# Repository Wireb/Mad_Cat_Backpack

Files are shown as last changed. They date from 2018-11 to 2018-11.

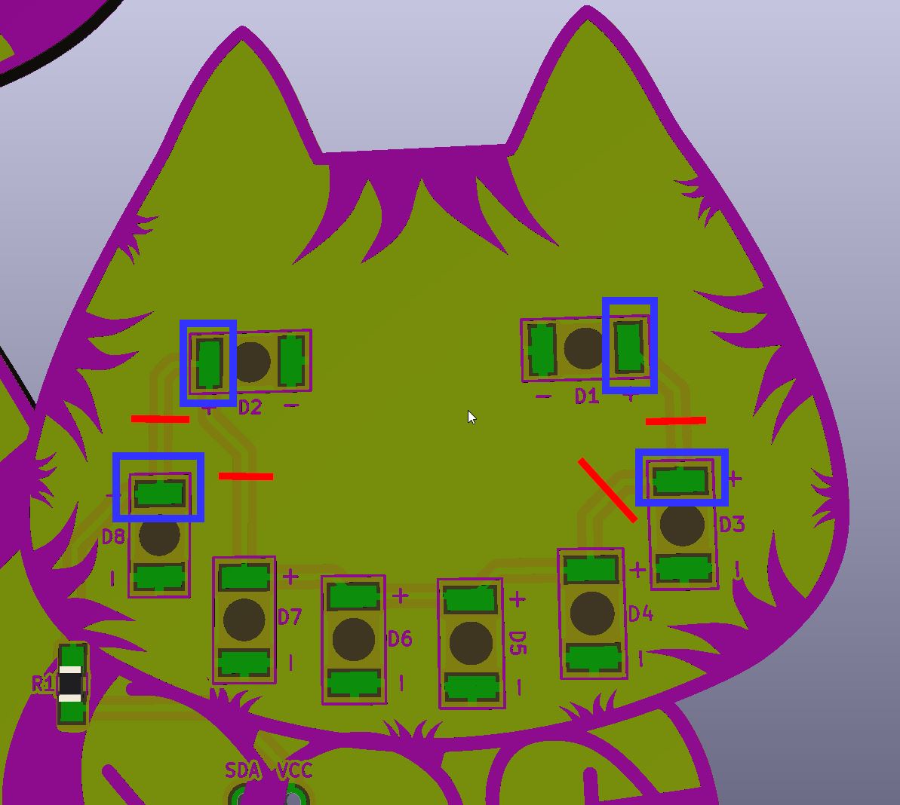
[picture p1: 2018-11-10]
Mad_Cat_modificatons.jpg

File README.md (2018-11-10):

# Mad Cat Backpack
The Mad Cat Backpack is a animation upgrade for Mr TwinkleTwinkie's Mad Cat SAOs.
 
License is MIT so do what you want with it just don't litigate me. 

Current firmware runs a loop that waits a random amount of time between 0 and 8 minutes then picks a random animation. 

Current animations:
1. classic fade out fade in (random off delay)
2. blink / wink (random length random eye (left, right, or both) 
3. lip lick rights
4. lip lick left
5. piano teeth (random number of loops) 
6. eye bobble (random number of loops)
7. talking (random number of loops) 
8. sparkles (all random) 

Animations are NOT weighted evenly. Blinking has a higher probability then the others while sparkles has the least. 

Total code space use is ~36% so plenty of space for more animations if wanted. 

**NOTE** 
- When running off 5V power the LEDs are borderline too bright. Replace the 200 ohm resistors with a larger value to reduce brightness.

## KiCad
This is a KiCad 5.0 project. 
PCBs are also posed on OSHpark here: https://www.oshpark.com/shared_projects/GfiURq3q

## MplabX
This is a mplabX 5.05 project. All programming / debug was done with a PicKit4.
The firmware source is all contained in mad_cat_backpack_v0.asm 
If you just want to program a backpack using mad_cat_backpack.X.production.hex in microchip IPE is the fastest way. 

## Documentation
There is not much for documentation on this one. 

First you need a Mad Cat SAO from Mr TwinkleTwinkie:
- https://www.tindie.com/products/twinkletwinkie/twinkletwinkies-badgelife-sao-add-on-4/
- https://hackaday.io/project/159523-mad-cat

Next you need a backpack PCB:
- https://www.oshpark.com/shared_projects/GfiURq3q

Parts list for the backpack are:
 - 1x PIC16F1503-I/SL https://www.digikey.com/product-detail/en/microchip-technology/PIC16F1503-I-SL/PIC16F1503-I-SL-ND/2772041
 - 1x 10uF 10V or greater 0805 ceramic cap https://www.digikey.com/product-detail/en/samsung-electro-mechanics/CL21A106KPFNNNG/1276-6456-1-ND/5958084
 - 8x 200 ohm 0805 resistors (see note above about brightness) https://www.digikey.com/product-detail/en/yageo/AC0805JR-07200RL/YAG3769CT-ND/6006618
 - Optional 1x UJ2-MBH-1-SMT-TR mini USB jack https://www.digikey.com/product-detail/en/cui-inc/UJ2-MBH-1-SMT-TR/102-4003-1-ND/6187925
 - 8x white LEDs (reused the ones from the Mad Cat kit) 

 Assemble the back pack first. I just used a iron and tweezers to assemble mine. The LED pads ARE oversized to match the footprints on the Mad Cat. Center the LED between the pads and bridge the solder over to the terminals. Make sure the solder bridges are not taller thant the body of the LED. 

 Load the firmware using the 5 pads in the center of the board. The square pin is pin 1. 

 Test the backpack by plugging in power or USB. THe smile should dim in first then the eyes if so all is working and ready for final assembly. 

 Before final assembly the Mad Cat PCB needs to be modified. Look at Mad_Cat_modifications.jpg Cut the 4 traces marked by a red line. Make sure they are fully open. 

 Line up the backpack on the Mad Cat PCB. I used a 4 pin header though both sets of SAO holes then visually lined up the D3 and D8 leds with the solder mask holes in the Mad Cat PCB. 

 Once everything is lined up solder the 4 pads marked in blue boxes on Mad_Cat_modifications.jpg between the Mad Cat and the backpack. To do this I used a fine point soldering iron tip and some 0.5mm diameter solder. There is just enough space to get under the edge and heat the pads and the 0.5mm solder is small enough to slide between the two boards. 

 Final option step is to add yarn between the LEDs to prevent light leakage. I used some dark colored yarn and dental threaders to thread sections between all the LEDs. When in place cut the ends of the yarn off ass close to the backpack as possible and tuck the excess under the backpack. I also wrapped a piece of yarn around the edge of the backpack to keep light from spilling out behind the Mad Cat SAO.

Copyright (c) 2018 Peter Shabino

Permission is hereby granted, free of charge, to any person obtaining a copy of this hardware, software, and associated documentation files 
(the "Product"), to deal in the Product without restriction, including without limitation the rights to use, copy, modify, merge, publish, 
distribute, sublicense, and/or sell copies of the Product, and to permit persons to whom the Product is furnished to do so, subject to the 
following conditions:

The above copyright notice and this permission notice shall be included in all copies or substantial portions of the Product.

THE PRODUCT IS PROVIDED "AS IS", WITHOUT WARRANTY OF ANY KIND, EXPRESS OR IMPLIED, INCLUDING BUT NOT LIMITED TO THE WARRANTIES OF 
MERCHANTABILITY, FITNESS FOR A PARTICULAR PURPOSE AND NONINFRINGEMENT. IN NO EVENT SHALL THE AUTHORS OR COPYRIGHT HOLDERS BE LIABLE 
FOR ANY CLAIM, DAMAGES OR OTHER LIABILITY, WHETHER IN AN ACTION OF CONTRACT, TORT OR OTHERWISE, ARISING FROM, OUT OF OR IN CONNECTION 
WITH THE PRODUCT OR THE USE OR OTHER DEALINGS IN THE PRODUCT.

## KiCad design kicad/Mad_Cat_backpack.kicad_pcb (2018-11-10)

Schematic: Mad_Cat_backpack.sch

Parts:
C1: 10uF; C_0805
D1, D2, D3, D4, D5, D6, D7, D8: LED; LED_OSRAM_TOPLED_LxT776
J1: USB_B_Mini; USB_Mini_B_Female_UJ2-MBH-1-SMT-TR
J2: PicKit; Pin_Header_Straight_1x05_Pitch2.54mm
R1, R2, R3, R4, R5, R6, R7, R8: 200; R_0805_HandSoldering
U1: PIC16F1503; SOIC-14_3.9x8.7mm_Pitch1.27mm
X1: Badgelife_shitty_connector; Badgelife-Shitty-2x2
icon1: Metroid; metroid

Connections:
+5V: C1.1, J1.1 (VBUS), J2.2, R1.1, R2.1, R3.1, R4.1, R5.1, R6.1, R7.1, R8.1, U1.1, X1.1
GND: C1.2, J1.5 (GND), J1.6 (Shield), J2.3, U1.14, X1.2
unnamed: D1.1, U1.2
unnamed: D1.2, R2.2
unnamed: D2.1, U1.7
unnamed: D2.2, R3.2
unnamed: D3.1, U1.3
unnamed: D3.2, R1.2
unnamed: D4.1, U1.10
unnamed: D4.2, R8.2
unnamed: D5.1, U1.9
unnamed: D5.2, R7.2
unnamed: D6.1, U1.8
unnamed: D6.2, R6.2
unnamed: D7.1, U1.5
unnamed: D7.2, R5.2
unnamed: D8.1, U1.6
unnamed: D8.2, R4.2
unnamed: J2.1, U1.4
unnamed: J2.4, U1.13
unnamed: J2.5, U1.12

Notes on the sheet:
Copyright (c) 2018 Peter Shabino Permission is hereby granted, free of charge, to any person obtaining a copy of this hardware, software, and associated documentation files (the "Product"), to deal in the Product without restriction, including without limitation the rights to use, copy, modify, mer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

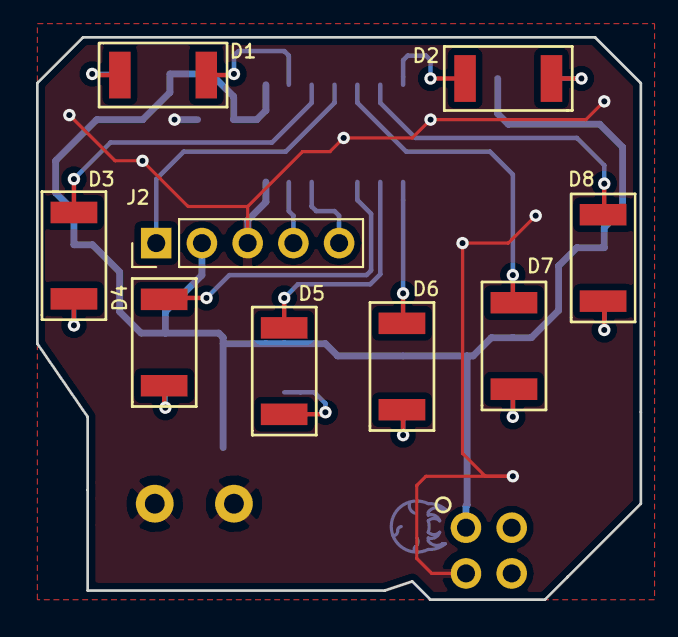
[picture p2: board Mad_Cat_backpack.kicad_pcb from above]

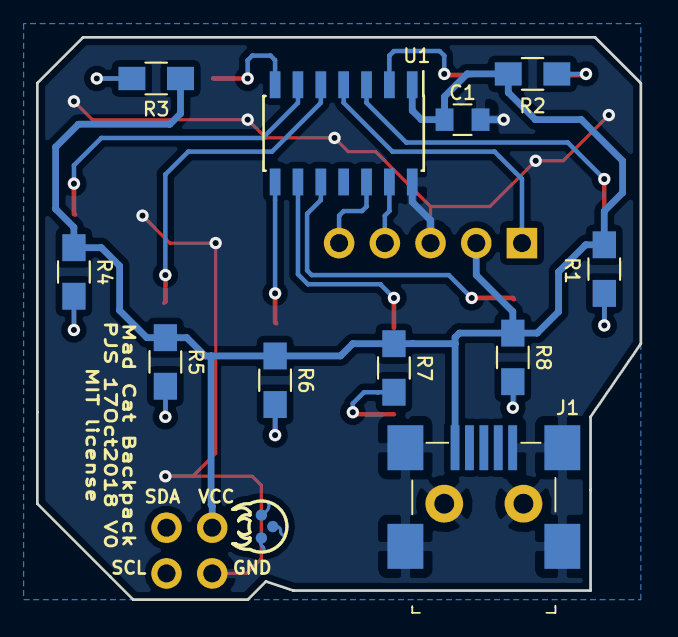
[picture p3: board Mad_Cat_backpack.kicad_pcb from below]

Board: 2 copper layers, 33.5 x 31.2 mm, 22 parts (12 on the bottom side), 21 nets.

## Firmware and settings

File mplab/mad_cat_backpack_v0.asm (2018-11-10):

;#########################################################################################################################################################
;Copyright (c) 2018 Peter Shabino
;
;Permission is hereby granted, free of charge, to any person obtaining a copy of this hardware, software, and associated documentation files 
;(the "Product"), to deal in the Product without restriction, including without limitation the rights to use, copy, modify, merge, publish, 
;distribute, sublicense, and/or sell copies of the Product, and to permit persons to whom the Product is furnished to do so, subject to the 
;following conditions:
;
;The above copyright notice and this permission notice shall be included in all copies or substantial portions of the Product.
;
;THE PRODUCT IS PROVIDED "AS IS", WITHOUT WARRANTY OF ANY KIND, EXPRESS OR IMPLIED, INCLUDING BUT NOT LIMITED TO THE WARRANTIES OF 
;MERCHANTABILITY, FITNESS FOR A PARTICULAR PURPOSE AND NONINFRINGEMENT. IN NO EVENT SHALL THE AUTHORS OR COPYRIGHT HOLDERS BE LIABLE 
;FOR ANY CLAIM, DAMAGES OR OTHER LIABILITY, WHETHER IN AN ACTION OF CONTRACT, TORT OR OTHERWISE, ARISING FROM, OUT OF OR IN CONNECTION 
;WITH THE PRODUCT OR THE USE OR OTHER DEALINGS IN THE PRODUCT.
;#########################################################################################################################################################
; 02Nov18 V0 PJS New
; 04Nov18 V1 PJS 8 base animations in with random rotations and delays. 
    
#define	CODE_VER_STRING "Peter Shabino 04Nov18 code for Mad Cat Backpack V1 www.wire2wire.org!" ;Just in ROM !!! update vars below with true level!!


;****************************************************************************************
; port list [SSOP28]
; Vss(14)
; Vdd(1)
; RA0(13)	[ICSPDAT]
; RA1(12)	[ICSPCLK]
; RA2(11)	
; RA3(4)	[#MCLR]
; RA4(3)	led tooth 1 left
; RA5(2)	led left eye
; RC0(10)	led tooth 2
; RC1(9)	led tooth 3
; RC2(8)	led tooth 4
; RC3(7)	led right eye
; RC4(6)	led tooth 6 right
; RC5(5)	led tooth 5
;****************************************************************************************

	
; PIC16F1503 Configuration Bit Settings
#include "p16f1503.inc"
; CONFIG1
; __config 0xFF04
 __CONFIG _CONFIG1, _FOSC_INTOSC & _WDTE_OFF & _PWRTE_ON & _MCLRE_OFF & _CP_ON & _BOREN_ON & _CLKOUTEN_OFF
; CONFIG2
; __config 0xF7FF
 __CONFIG _CONFIG2, _WRT_OFF & _STVREN_ON & _BORV_LO & _LPBOR_ON & _LVP_ON	
 
 
 
;------------------
; constants
;------------------	
PWM_DELAY		equ 0x7D
	
;------------------
; vars (0x20 - 0x6f) bank 0
;------------------
right_eye		equ 0x20
left_eye		equ 0x21
tooth1			equ 0x22
tooth2			equ 0x23
tooth3			equ 0x24
tooth4			equ 0x25
tooth5			equ 0x26
tooth6			equ 0x27
pwm_cnt			equ	0x28
delay_l			equ 0x29
delay_h			equ	0x2A
counter1		equ 0x2B
temp			equ 0x2C
LFSR_0			equ	0x2D			
LFSR_1			equ	0x2E			
LFSR_2			equ	0x2F			
LFSR_3			equ	0x30	
LFSR_count		equ 0x31
counter2		equ 0x32
 
 
;------------------
; vars (0x70 - 0x7F) global regs
;------------------


 
;put the following at address 0000h
	org     0000h
	goto    START			    ;vector to initialization sequence

;put the following at address 0004h
	org     0004h
	clrf	PCLATH				; this MUST be cleared before the IRQ goto else will jump to god knows where. 
	goto    IRQ			    

; stuff in the 	code description at the top of the code. 
	de	CODE_VER_STRING
	
;###########################################################################################################################
; intrupt routine
;###########################################################################################################################
IRQ		
	; following regs are autosaved
	; W
	; STATUS (except TO and PD)
	; BSR
	; FSR
	; PCLATH
	
	
	;------------------
	clrf    BSR			    ; bank 0
	;------------------
	btfss	INTCON, TMR0IF
	goto	IRQ_not_tmr0
	
	; update PWM timer
	incf	pwm_cnt, F
	btfss	STATUS, Z
	goto	IRQ_tmr0_pwm_not_zero
	movf	left_eye, W
	btfss	STATUS, Z
	bcf		PORTA, 5
	movf	right_eye, W
	btfss	STATUS, Z
	bcf		PORTC, 3
	movf	tooth1, W
	btfss	STATUS, Z
	bcf		PORTA, 4
	movf	tooth2, W
	btfss	STATUS, Z
	bcf		PORTC, 0
	movf	tooth3, W
	btfss	STATUS, Z
	bcf		PORTC, 1
	movf	tooth4, W
	btfss	STATUS, Z
	bcf		PORTC, 2
	movf	tooth5, W
	btfss	STATUS, Z
	bcf		PORTC, 5
	movf	tooth6, W
	btfss	STATUS, Z
	bcf		PORTC, 4	
	goto	IRQ_tmr0_done
	
IRQ_tmr0_pwm_not_zero	
	movf	pwm_cnt, W
	subwf	left_eye, W
	btfss	STATUS, C
	bsf		PORTA, 5
	movf	pwm_cnt, W
	subwf	right_eye, W
	btfss	STATUS, C
	bsf		PORTC, 3
	movf	pwm_cnt, W
	subwf	tooth1, W
	btfss	STATUS, C
	bsf		PORTA, 4
	movf	pwm_cnt, W
	subwf	tooth2, W
	btfss	STATUS, C
	bsf		PORTC, 0
	movf	pwm_cnt, W
	subwf	tooth3, W
	btfss	STATUS, C
	bsf		PORTC, 1
	movf	pwm_cnt, W
	subwf	tooth4, W
	btfss	STATUS, C
	bsf		PORTC, 2
	movf	pwm_cnt, W
	subwf	tooth5, W
	btfss	STATUS, C
	bsf		PORTC, 5
	movf	pwm_cnt, W
	subwf	tooth6, W
	btfss	STATUS, C
	bsf		PORTC, 4	
	
IRQ_tmr0_done	
	movlw	PWM_DELAY		; prime timer 0 with inital value
	movwf	TMR0
	bcf		INTCON, TMR0IF	
IRQ_not_tmr0
	
	
	btfss	PIR1, TMR1IF
	goto	IRQ_not_tmr1
	bcf		PIR1, TMR1IF

	; check if delay is already 0
	movf	delay_l, W
	btfss	STATUS,Z
	goto	IRQ_tmr1_not_zero
	movf	delay_h, W
	btfsc	STATUS,Z
	goto	IRQ_not_tmr1
IRQ_tmr1_not_zero	
	; subtract 1
	movlw	0x01
	subwf	delay_l, F
	btfss	STATUS, C
	decf	delay_h, F
IRQ_not_tmr1
	
	retfie
;###########################################################################################################################
; end of IRQ code
;###########################################################################################################################	
	
START
	; init crap
	;------------------
	clrf    BSR			    ; bank 0
	;------------------
	clrf	INTCON			; disable interupts
	
	; init timers
	movlw	PWM_DELAY		; prime timer 0 with inital value
	movwf	TMR0
	clrf	T1GCON			; disable timer 1 gate control
	bcf		PIR1, TMR1IF	; clear interrupt
	movlw	0x31			; timer1 Fosc/4, 1:8 pre, on
	movwf	T1CON
	movlw	0xFF
	movwf	PR2
	movlw	0x3E			; timer 2 on, 1:8 post, 1:16 pre scaler
	movwf	T2CON
	clrf	TMR2
	
	; init LFSR
	movlw	0x55
	movwf	LFSR_0
	movwf	LFSR_1
	movwf	LFSR_2
	movwf	LFSR_3	

	; init leds
	clrf	right_eye
	clrf	left_eye
	clrf	tooth1
	clrf	tooth2
	clrf	tooth3
	clrf	tooth4
	clrf	tooth5
	clrf	tooth6
	
	;------------------
	movlw	d'3'
	movwf	BSR		
	;------------------
	clrf	ANSELA
	clrf	ANSELC

	;------------------
	movlw	d'2'
	movwf	BSR		
	;------------------
	movlw	0x30
	movwf	LATA
	movlw	0x3F
	movlw	0x00
	movwf	LATC

	;------------------
	movlw	d'1'
	movwf	BSR		
	;------------------
	clrf	LATA			    ; 0 = output
	clrf	LATC	
	movlw	0x78
	movwf	OSCCON
	movlw	0xD8				; timer 0 internal clock, prescaler to timer 0, 2 divider
	movwf	OPTION_REG
	bsf		PIE1, TMR1IE		; enable timer 1 interrupt
	
	;------------------
	clrf    BSR					; bank 0
	;------------------
	movlw	0xE0				; global, PE, and Timer 0 on
	movwf	INTCON			    ; enable interrupts

	
	goto	START_ANIMATION
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

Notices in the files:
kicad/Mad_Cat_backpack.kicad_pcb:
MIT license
